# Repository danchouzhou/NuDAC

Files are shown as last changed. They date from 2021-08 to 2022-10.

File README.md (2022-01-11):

# NuDAC
A USB codec based on Nuvoton M482ZGCAE MCU and NAU88L25YGB I2S audio codec
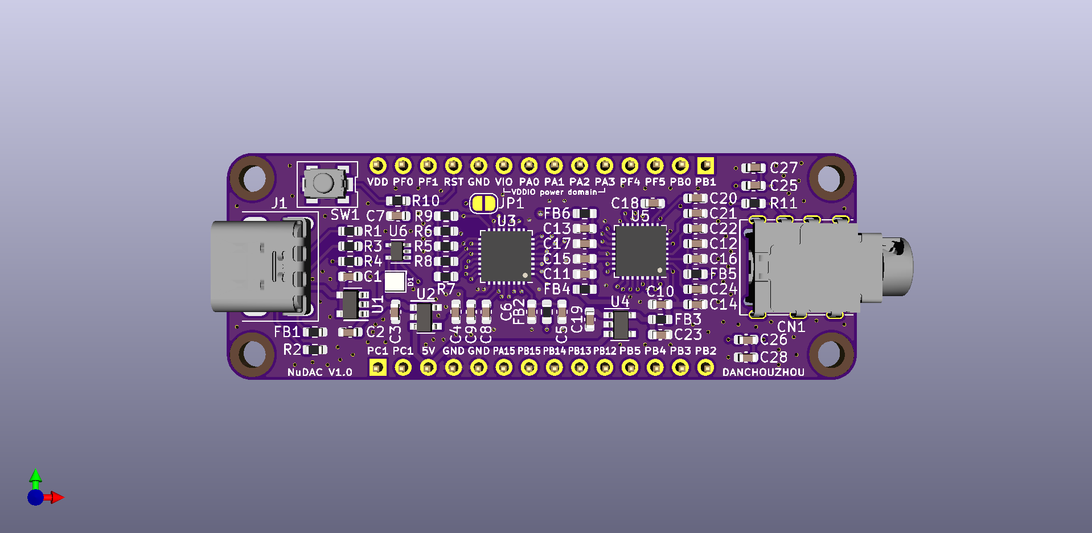
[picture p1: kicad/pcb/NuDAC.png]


## Fetures
### Design
- Provide almost all of MCU I/O on pin header  
- Low noise & fail-safe power design  
- Four-layer PCB  
- Low profile mid mount THT phone jack  
- On board APA ELECTRONIC CO., LTD. patented RGB LED with level translator  
- Molex USB 2.0 through hole Type-C connector improve mechanical strength  
- Jump free Nu-Link connectivity
- Support semi-auto USB ISP (by pressing reset button) provide firmware update and secondary development without a programmer  
### Nuvoton M482ZGCAE microcontroller  
- ARM Cortex-M4 processor up to 192MHz with float point unit and DSP  
- 16-channel programable peripheral direct memory access  
- USB 2.0 full-speed with precise internal oscillator  
- Rich interface include UART, SPI, IIC, IIS, LIN
- 12-bit ADC and DAC
- 16-bit PWM
- True random number generator  
### Nuvoton NAU88L25YGB high performance audio codec
- On chip ground referenced Class-A/AB/G selectable headphone amplifier
- On chip DSP include DRC (Dynamic Range Compressor), and programmable biquad filters  
- 24-bit A/D and D/A signal processing unit, up to 192K sample rate  
- 124dB SNR (@ 1Vrms, 0dB gain, 1KHz)  
- THD+Noise -89dB (@ 32 ohm, 1KHz, 20mW)  
- 28mW output power (@ 32 ohm, 1% THD+N)  

## Specification
- 5V power supply: 4.5~5.5V, 1A max  
- 5V output capacity: 1A max
- VDD output capacity: 300mA max

## To clone this project
This project work with M480BSP submodule from Nuvoton corporation. You need to initialize submodules by passing ``--recurse-submodules`` to the ``git clone`` command.
```
git clone https://github.com/danchouzhou/NuDAC --recurse-submodules
```

## Prepare develop environment
1. Installing tools
```
sudo apt install kicad build-essential gcc-arm-none-eabi libtool libusb-1.0-0-dev
```
2. Build and install customize version of OpenOCD for Nuvoton devices
```
git clone https://github.com/OpenNuvoton/OpenOCD-Nuvoton.git
cd OpenOCD-Nuvoton
./bootstrap
./configure --enable-nulink
make
sudo make install
```

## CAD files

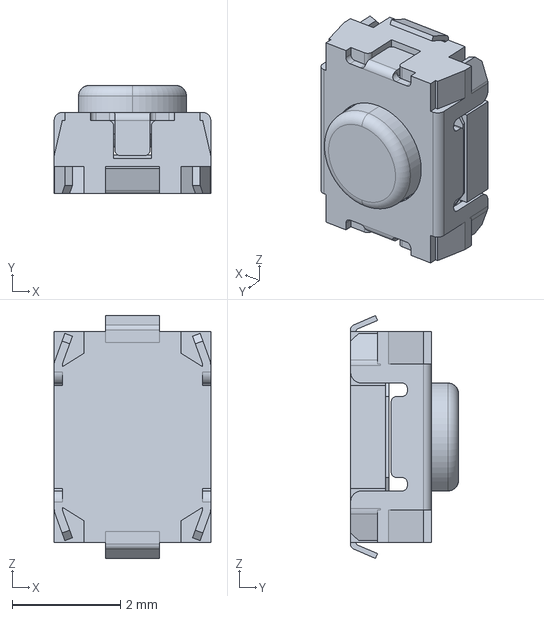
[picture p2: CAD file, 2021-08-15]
kicad/M480/PTS820J25MSMTRLFS.stp
2.90 x 2.00 x 4.50 mm

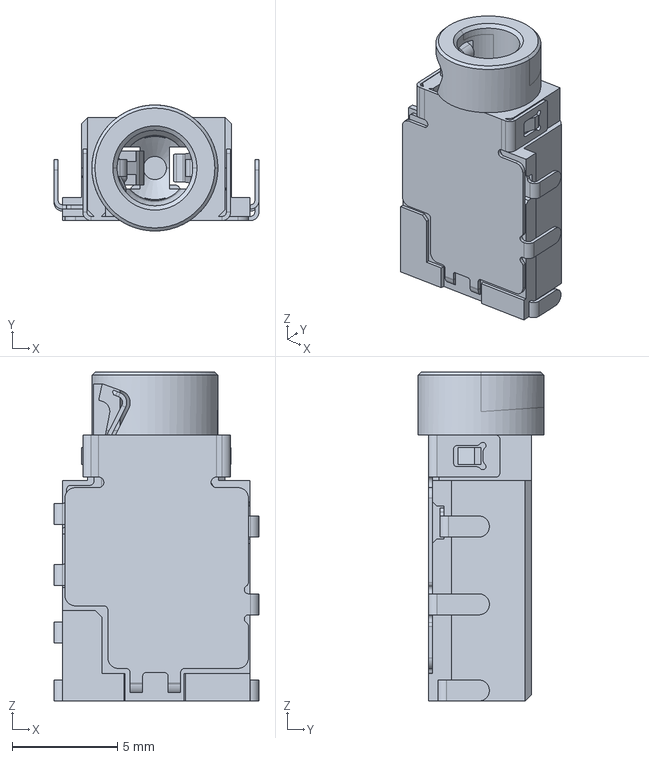
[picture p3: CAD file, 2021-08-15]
kicad/NAU88L25YGB/2SJ3080-000111F.stp
9.75 x 6.00 x 15.7 mm

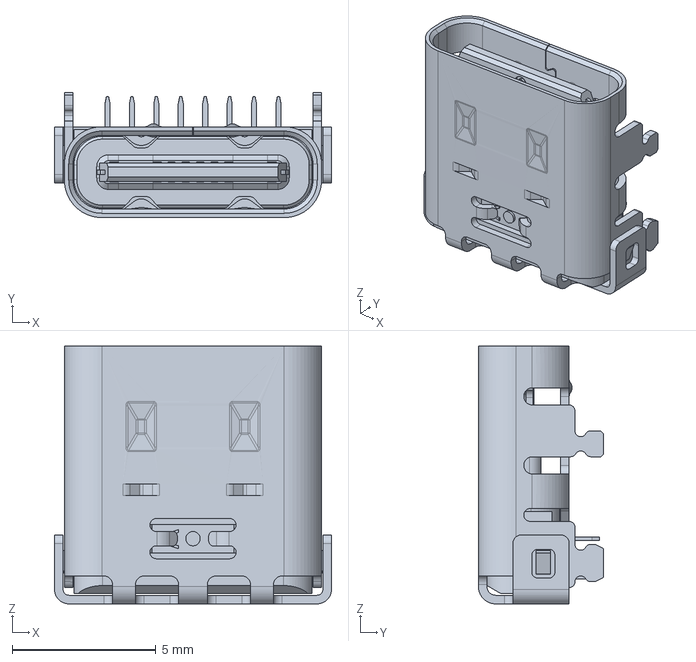
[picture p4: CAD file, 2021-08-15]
kicad/USB_CONN/2137160001.stp
9.64 x 4.36 x 8.97 mm

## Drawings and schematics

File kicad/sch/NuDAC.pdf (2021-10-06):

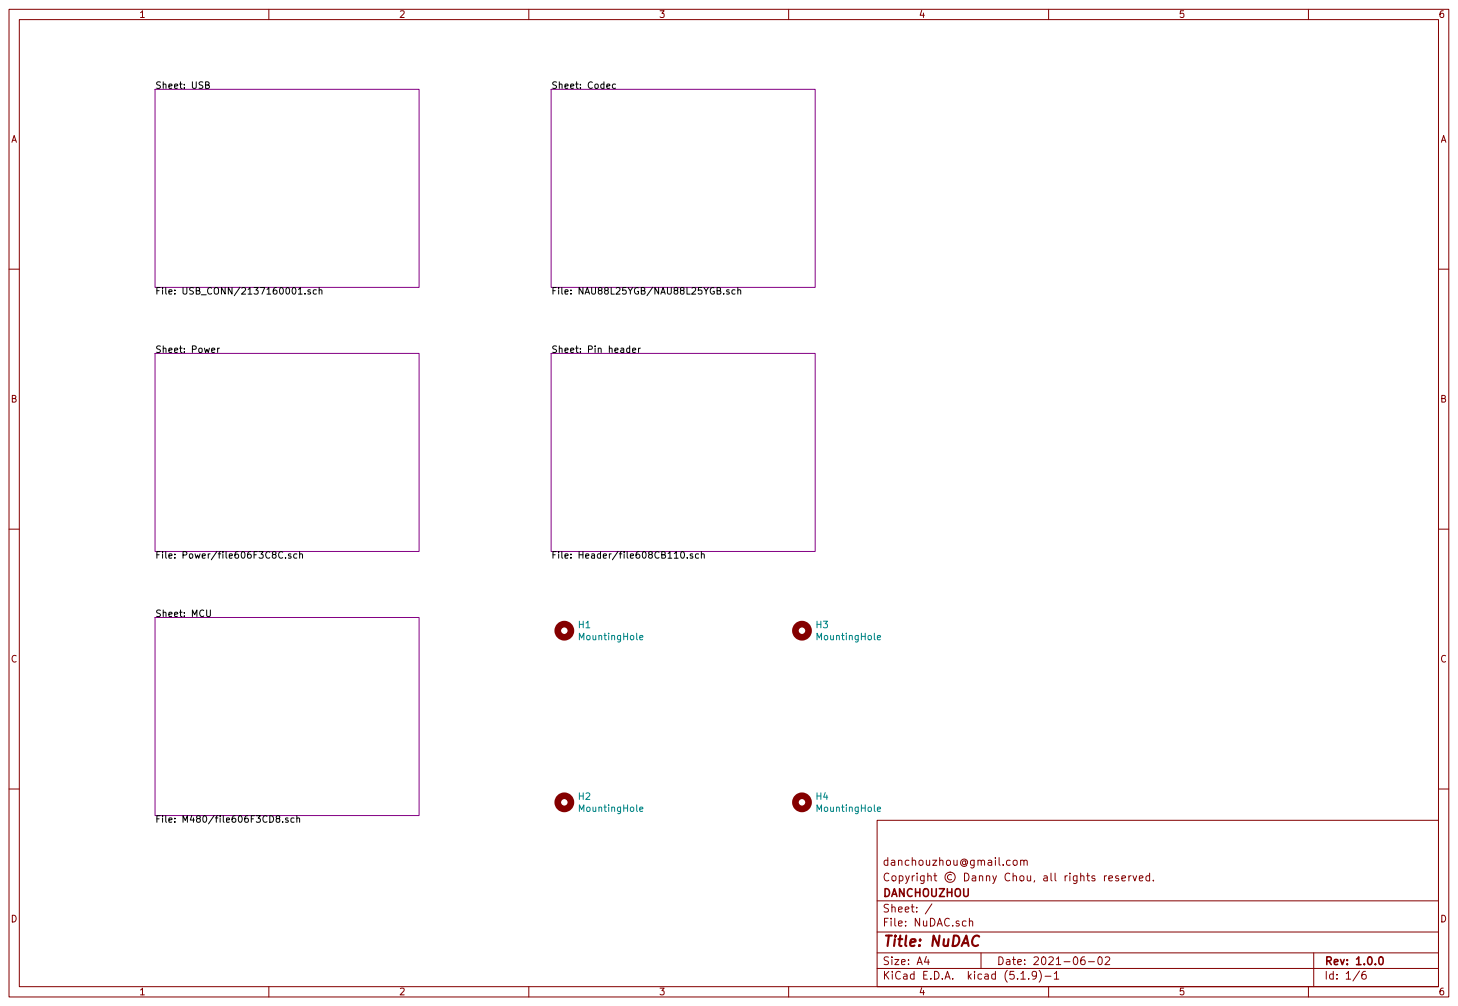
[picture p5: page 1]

File: USB_CONN/2137160001.sch Sheet: Power File: Power/file606F3C8C.sch Sheet: MCU

danchouzhou@gmail.com
Copyright © Danny Chou, all rights reserved.
File: NuDAC.sch Sheet: / DANCHOUZHOU

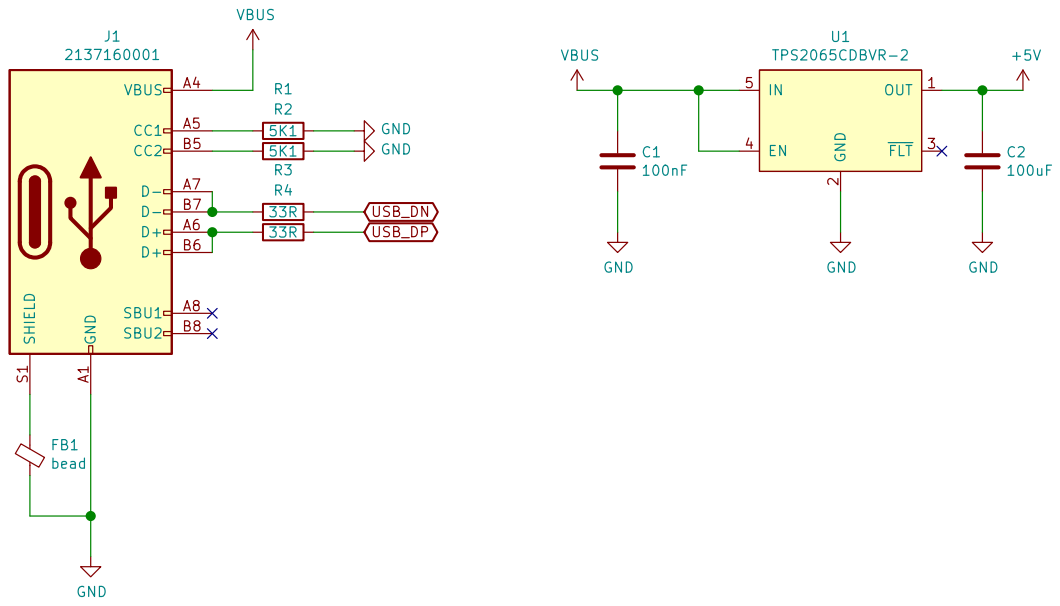
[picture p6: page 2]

danchouzhou@gmail.com
Copyright © Danny Chou, all rights reserved.
File: 2137160001.sch Sheet: /USB/ DANCHOUZHOU

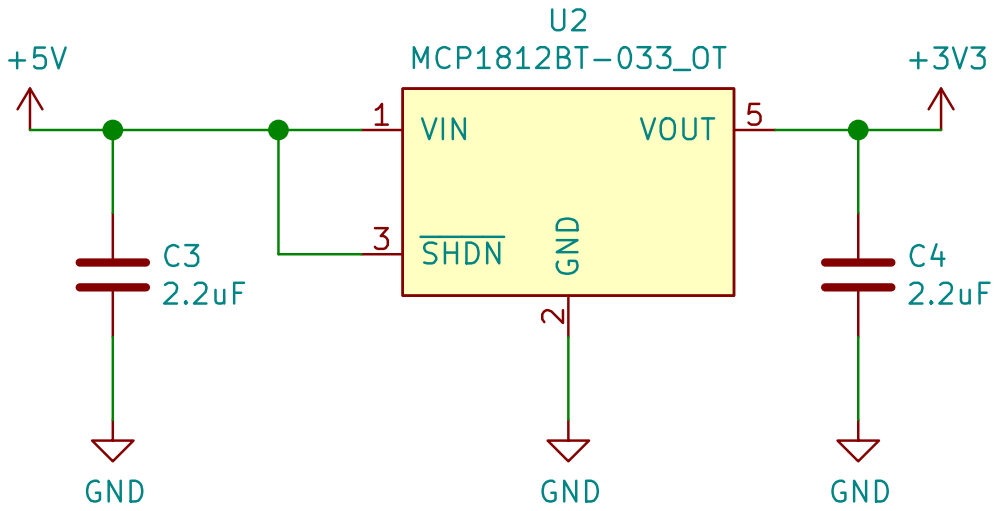
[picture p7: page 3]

danchouzhou@gmail.com
Copyright © Danny Chou, all rights reserved.
File: file606F3C8C.sch Sheet: /Power/ DANCHOUZHOU

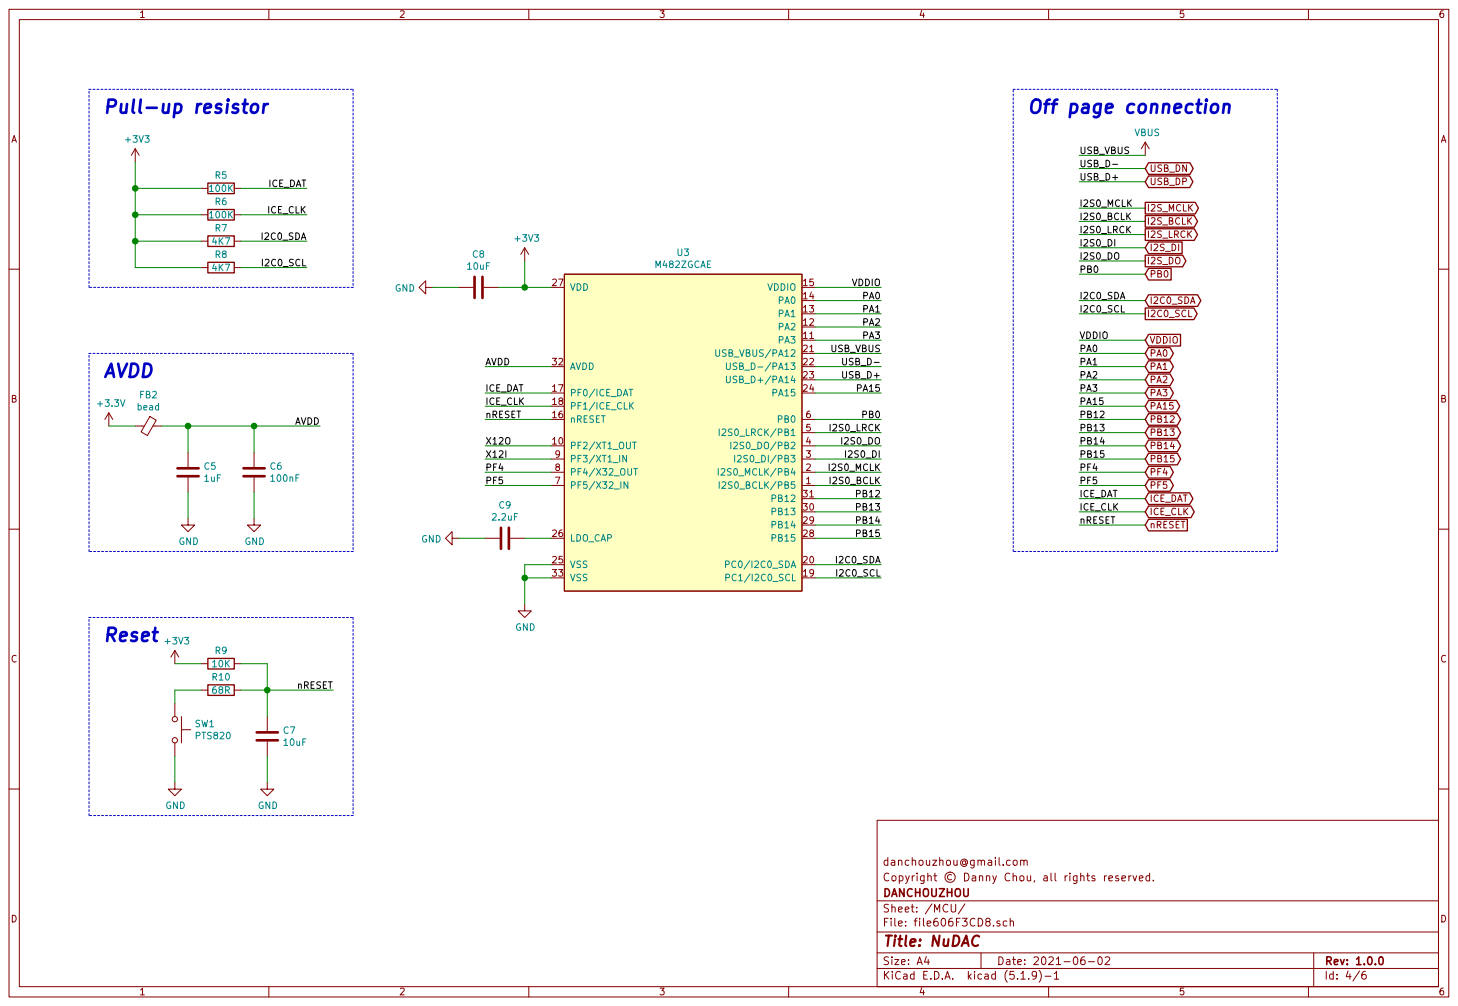
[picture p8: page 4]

danchouzhou@gmail.com
Copyright © Danny Chou, all rights reserved.
File: file606F3CD8.sch Sheet: /MCU/ DANCHOUZHOU

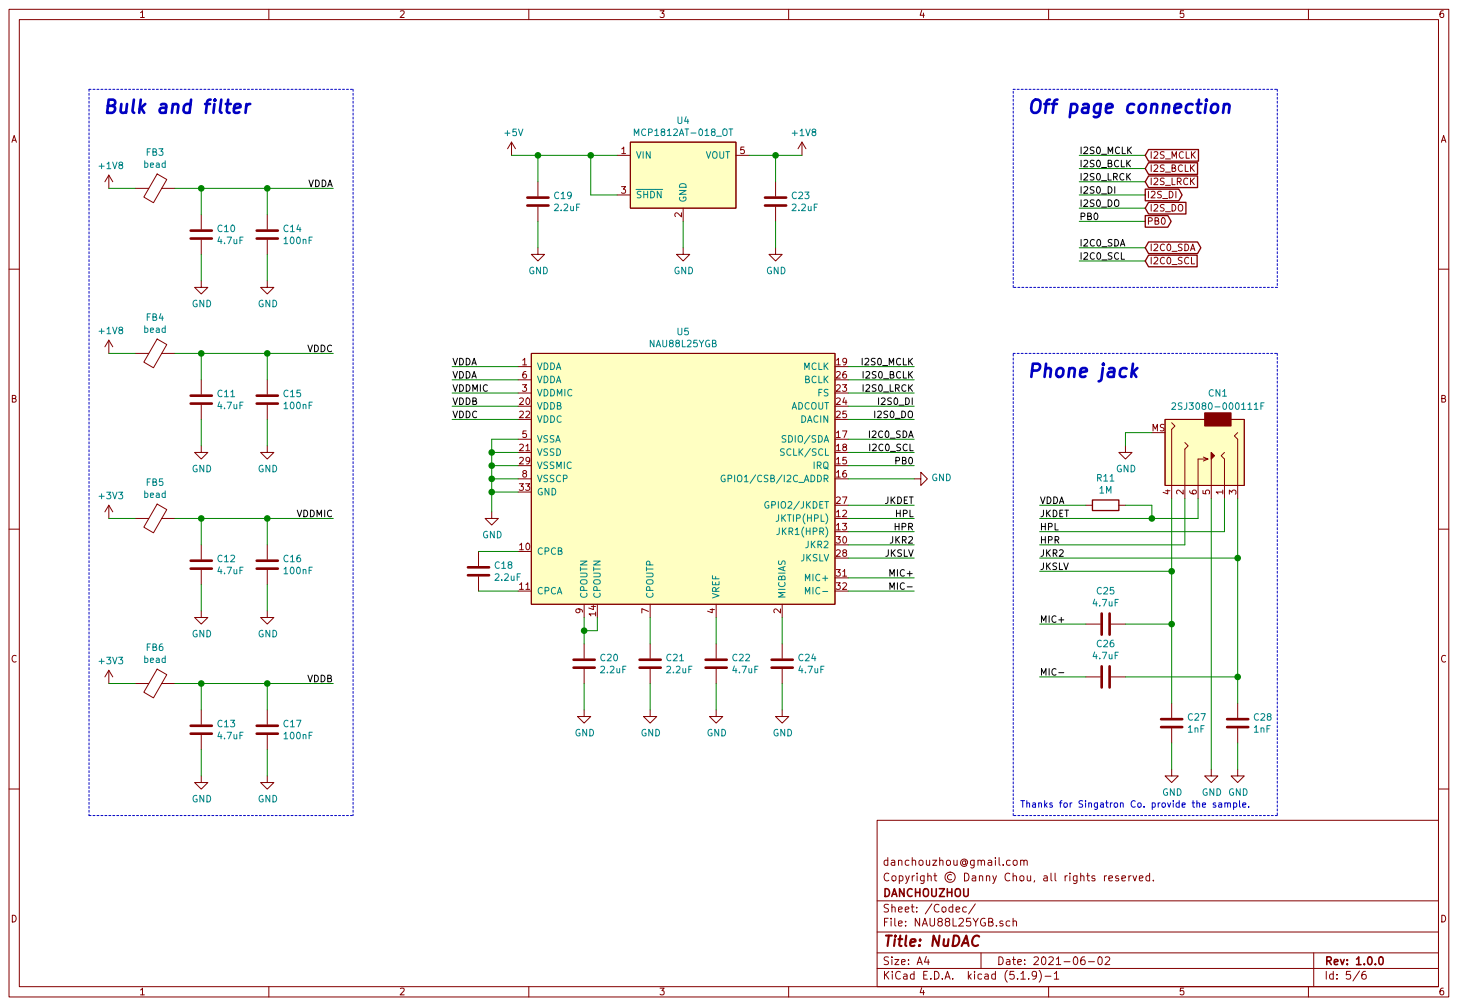
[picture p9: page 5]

2 SHDN 3 VOUT 5 U4 MCP1812AT-018_OT GND GND

Thanks for Singatron Co. provide the sample.

danchouzhou@gmail.com
Copyright © Danny Chou, all rights reserved.
File: NAU88L25YGB.sch Sheet: /Codec/ DANCHOUZHOU

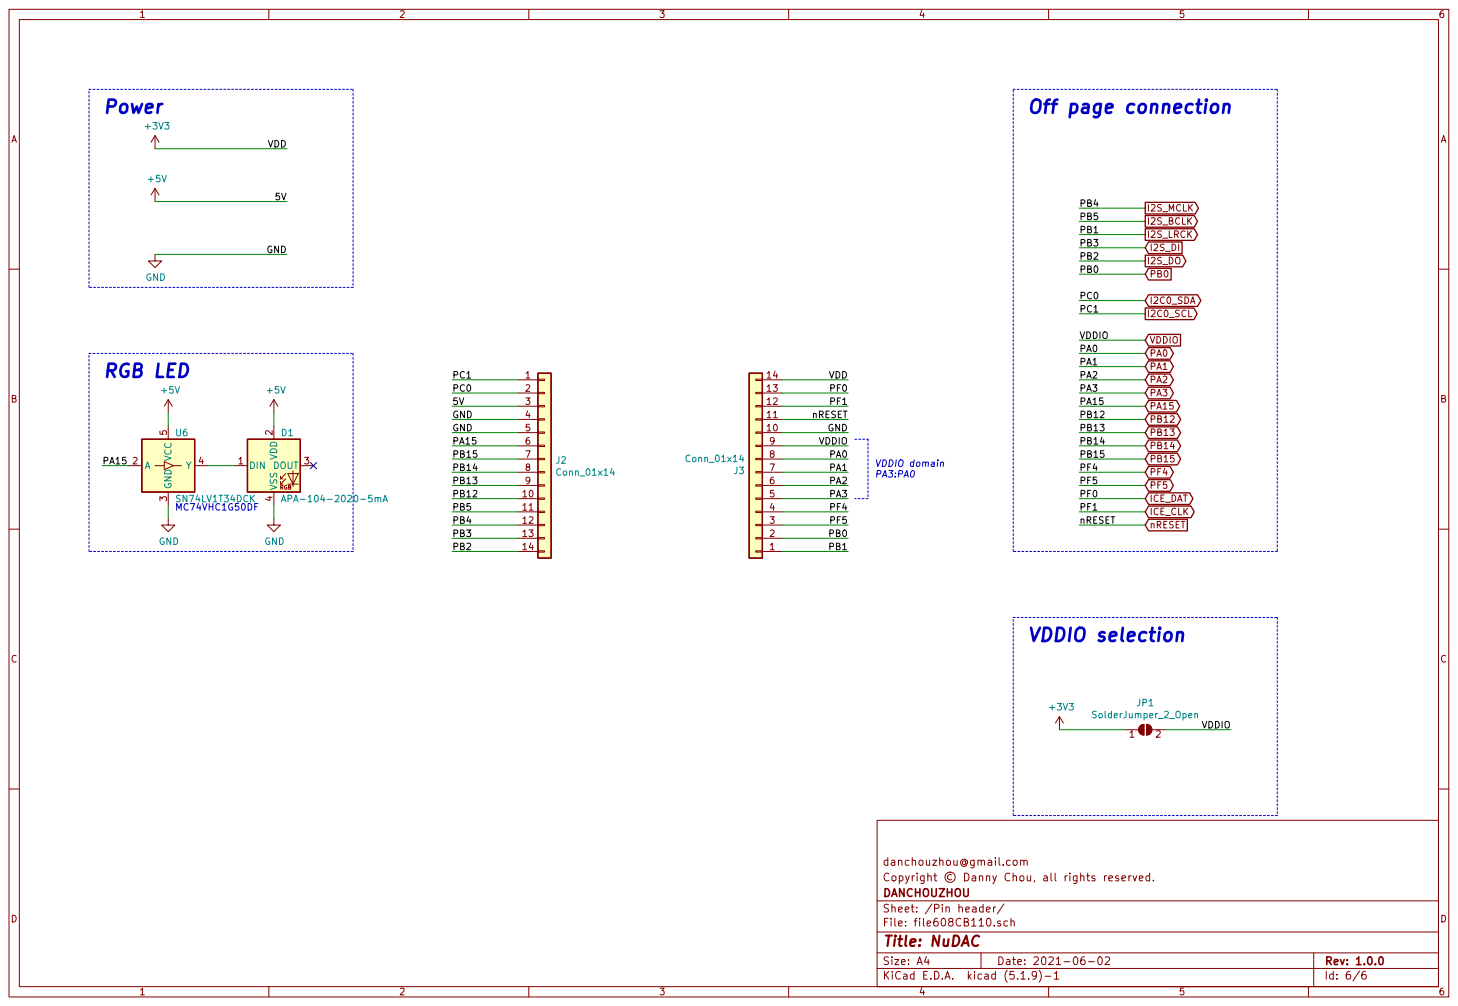
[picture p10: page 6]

danchouzhou@gmail.com
Copyright © Danny Chou, all rights reserved.
File: file608CB110.sch Sheet: /Pin header/ DANCHOUZHOU

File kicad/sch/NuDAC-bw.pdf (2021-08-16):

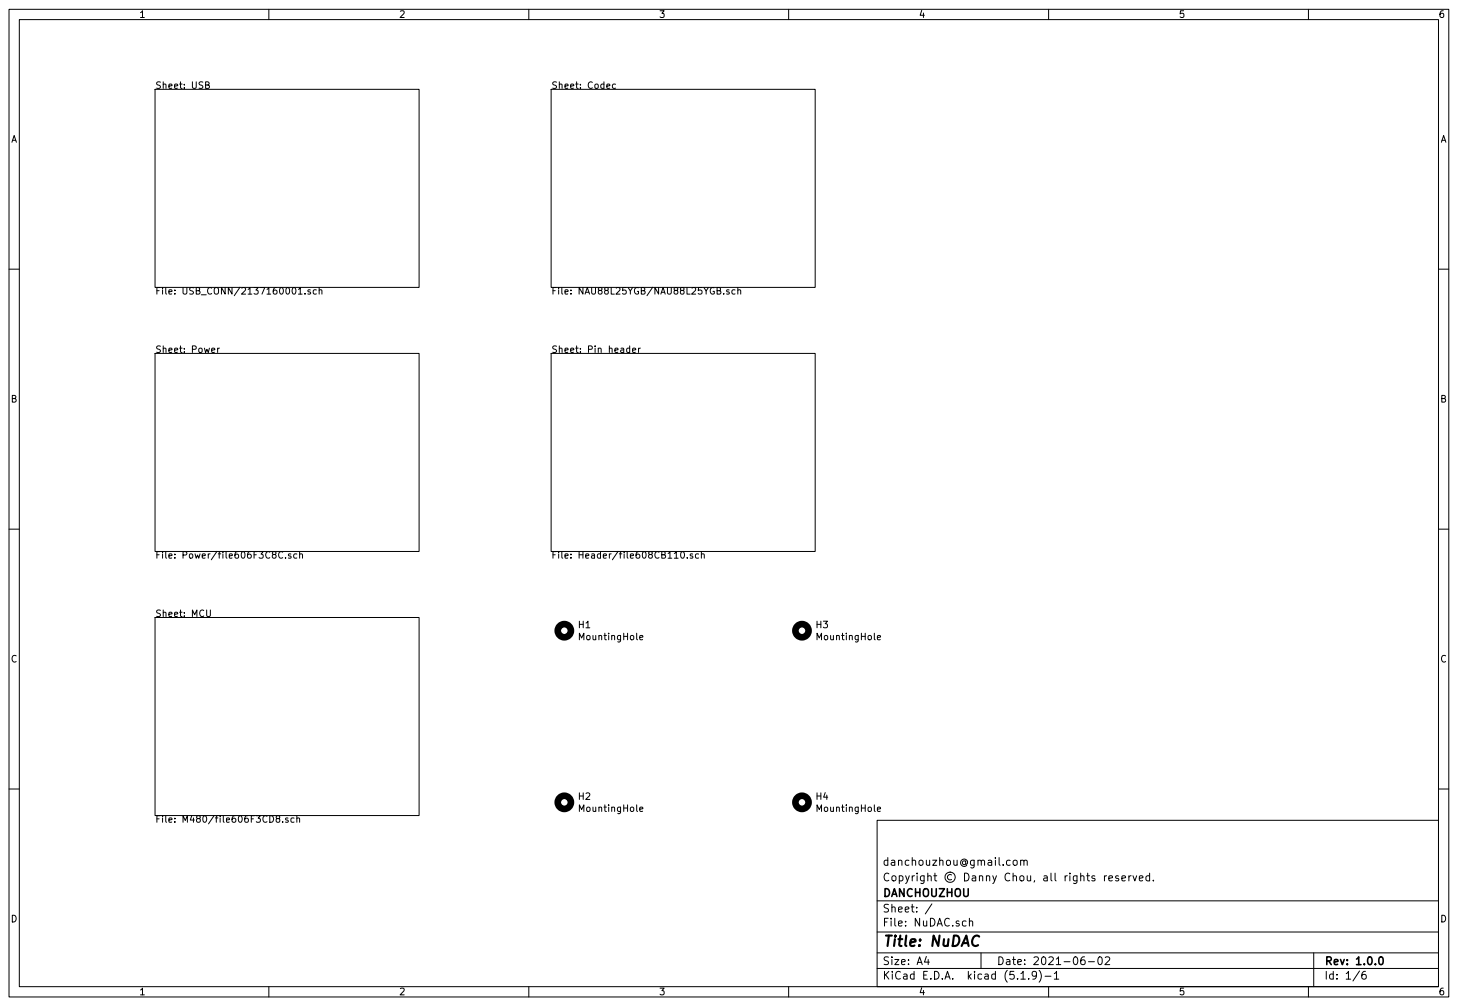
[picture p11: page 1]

File: USB_CONN/2137160001.sch Sheet: Power File: Power/file606F3C8C.sch Sheet: MCU

danchouzhou@gmail.com
Copyright © Danny Chou, all rights reserved.
File: NuDAC.sch Sheet: / DANCHOUZHOU

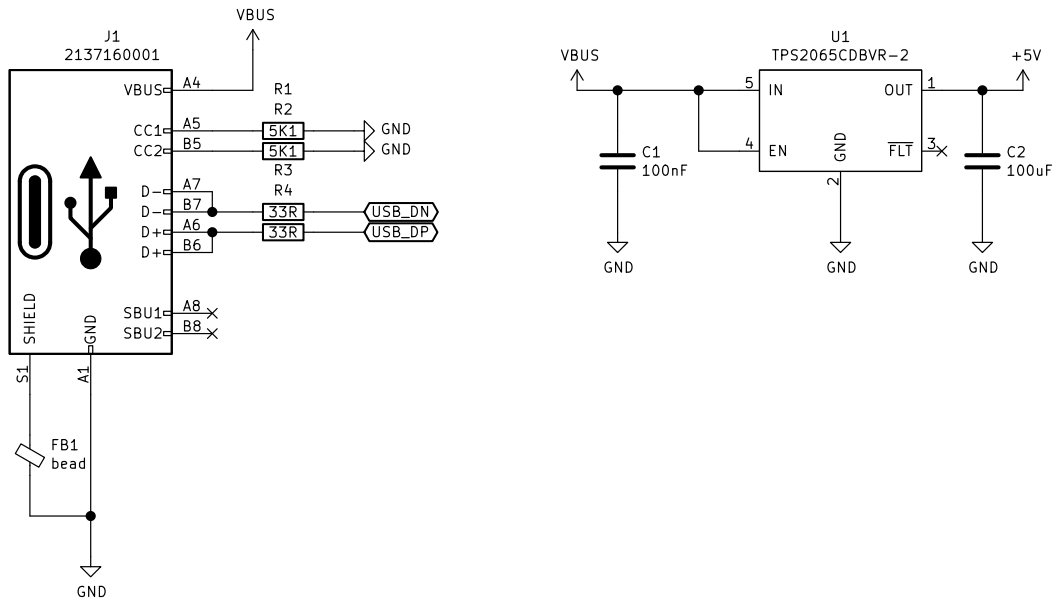
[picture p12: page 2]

danchouzhou@gmail.com
Copyright © Danny Chou, all rights reserved.
File: 2137160001.sch Sheet: /USB/ DANCHOUZHOU

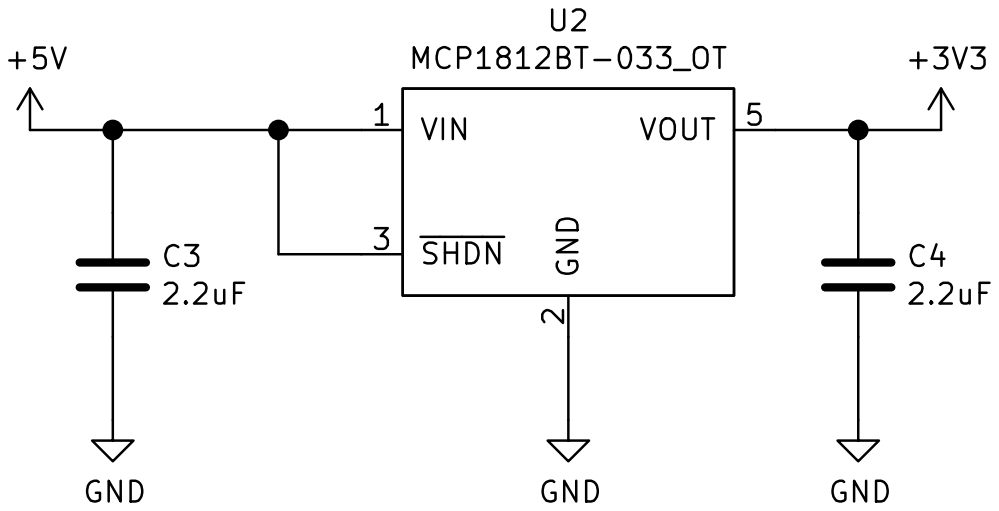
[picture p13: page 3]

danchouzhou@gmail.com
Copyright © Danny Chou, all rights reserved.
File: file606F3C8C.sch Sheet: /Power/ DANCHOUZHOU

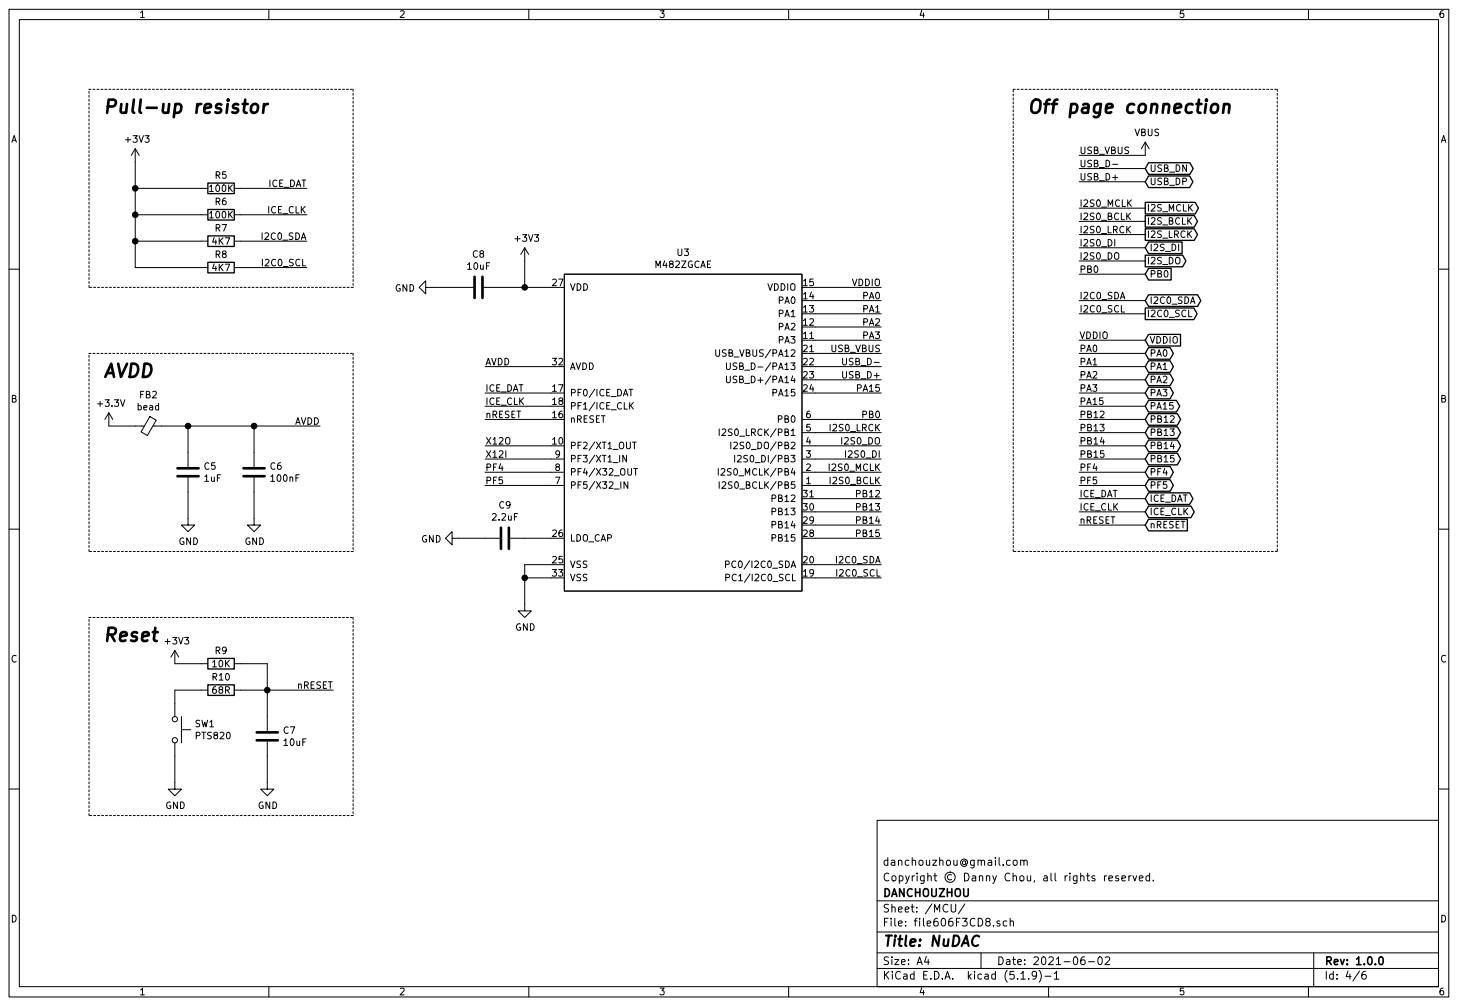
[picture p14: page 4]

danchouzhou@gmail.com
Copyright © Danny Chou, all rights reserved.
File: file606F3CD8.sch Sheet: /MCU/ DANCHOUZHOU

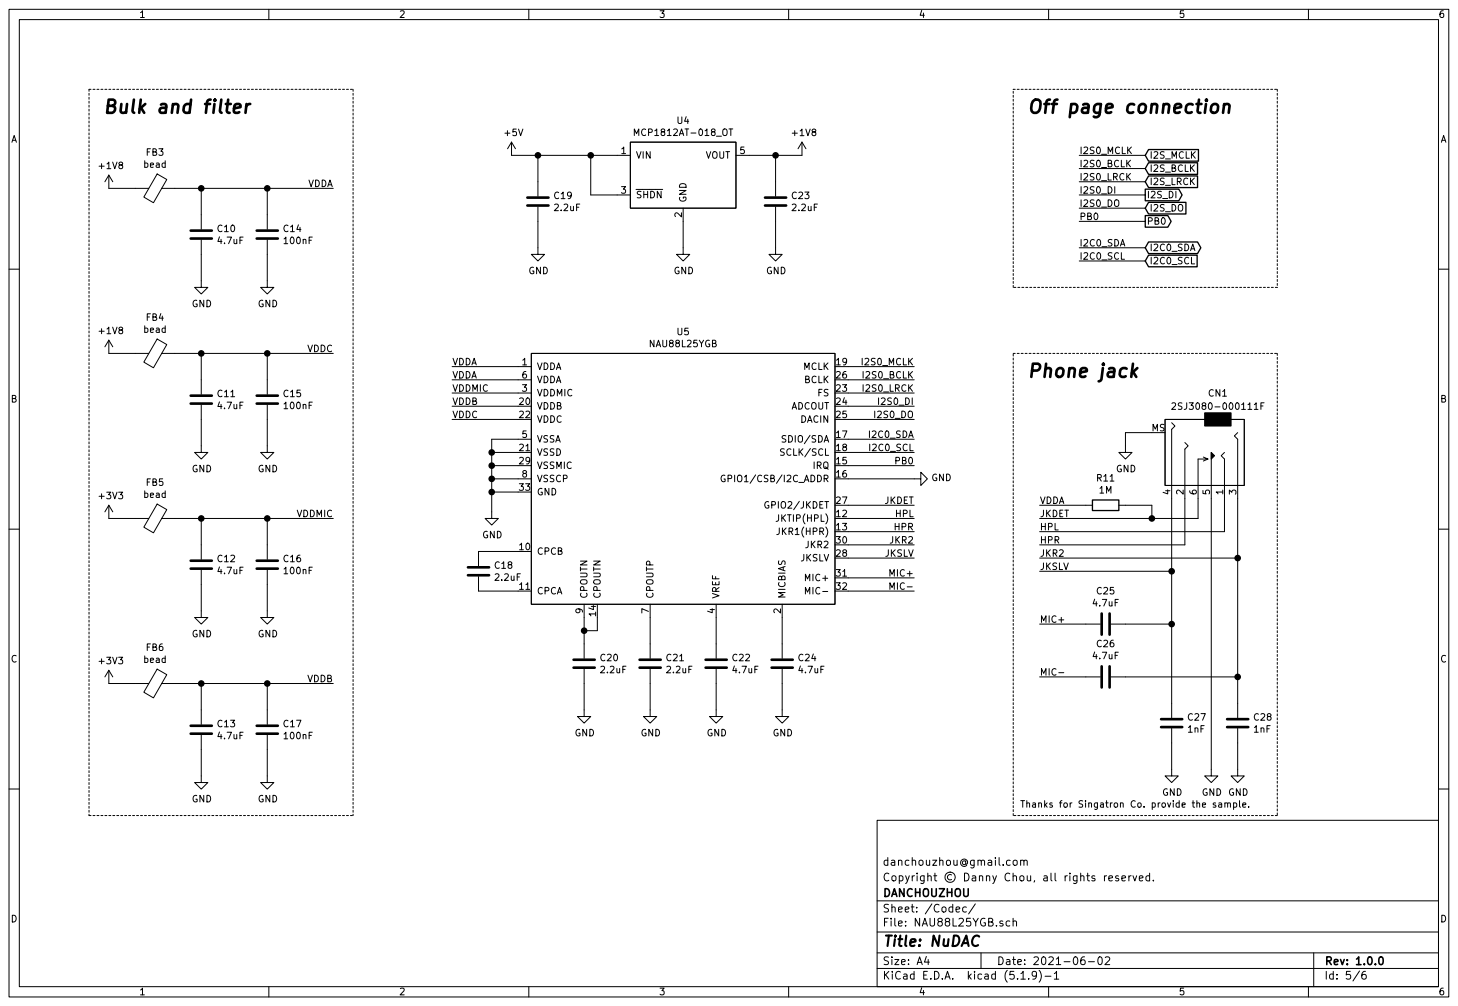
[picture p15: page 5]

2 SHDN 3 VOUT 5 U4 MCP1812AT-018_OT GND GND

Thanks for Singatron Co. provide the sample.

danchouzhou@gmail.com
Copyright © Danny Chou, all rights reserved.
File: NAU88L25YGB.sch Sheet: /Codec/ DANCHOUZHOU

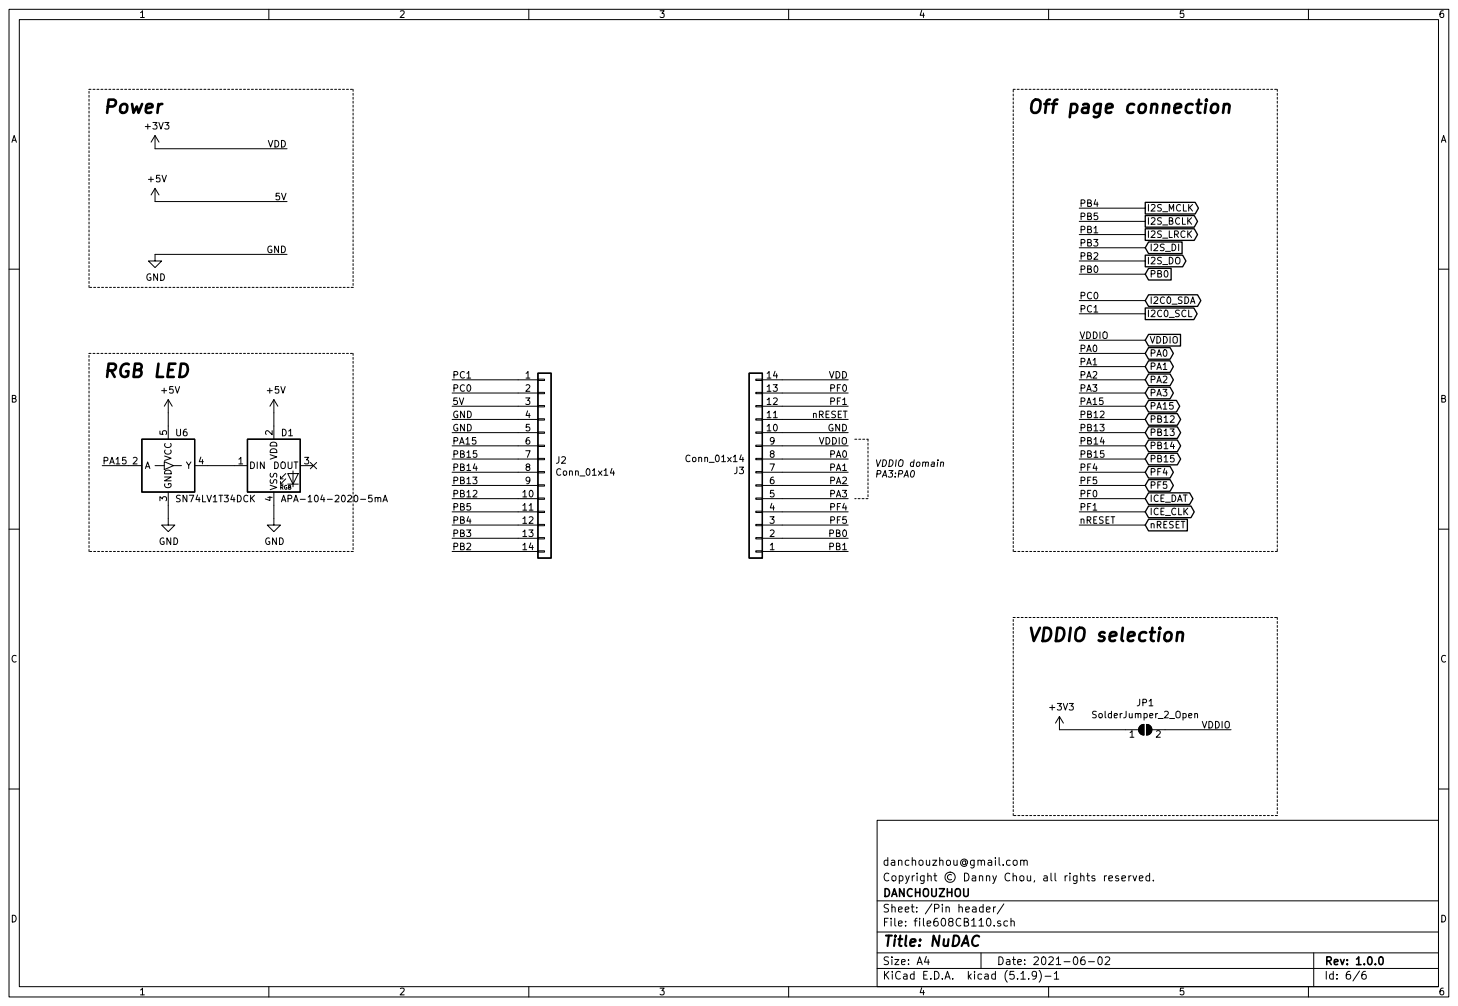
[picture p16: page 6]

VDDIO domain PA3:PA0 RGB LED

danchouzhou@gmail.com
Copyright © Danny Chou, all rights reserved.
File: file608CB110.sch Sheet: /Pin header/ DANCHOUZHOU

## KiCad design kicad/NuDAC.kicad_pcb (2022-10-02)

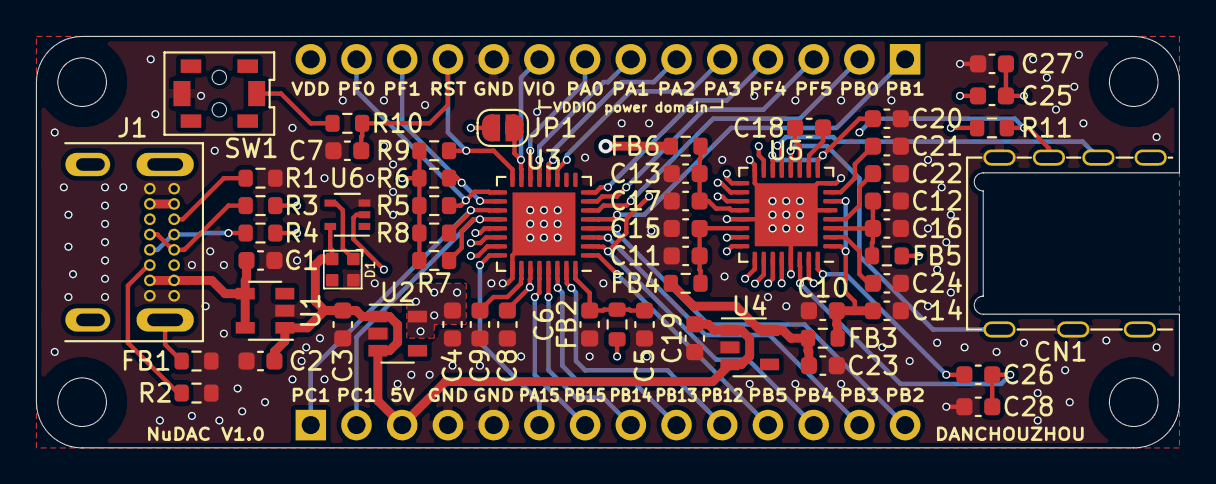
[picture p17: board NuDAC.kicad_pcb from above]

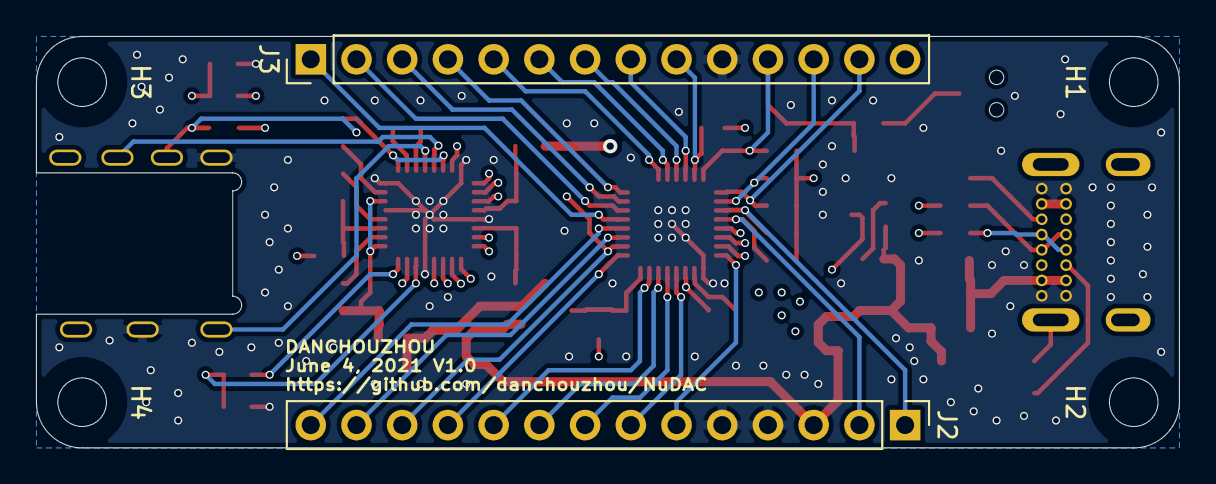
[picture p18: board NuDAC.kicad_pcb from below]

Board: 4 copper layers, 63.5 x 22.9 mm, 62 parts (6 on the bottom side), 56 nets.

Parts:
C1, C6, C14, C15, C16, C17: 100nF; C_0603_1608Metric
C2: 100uF; C_0603_1608Metric
C3, C4, C9, C18, C19, C20, C21, C23: 2.2uF; C_0603_1608Metric
C5: 1uF; C_0603_1608Metric
C7, C8: 10uF; C_0603_1608Metric
C10, C11, C12, C13, C22, C24, C25, C26: 4.7uF; C_0603_1608Metric
C27, C28: 1nF; C_0603_1608Metric
CN1: 2SJ3080-000111F
D1: APA-104-2020-5mA
FB1, FB2, FB3, FB4, FB5, FB6: bead; R_0603_1608Metric
H1, H2, H3, H4: MountingHole; MountingHole_2.7mm_M2.5_ISO7380
J1: 2137160001
J2, J3: Conn_01x14; PinHeader_1x14_P2.54mm_Vertical
JP1: SolderJumper_2_Open; SolderJumper-2_P1.3mm_Open_RoundedPad1.0x1.5mm
R1, R2: 5K1; R_0603_1608Metric
R3, R4: 33R; R_0603_1608Metric
R5, R6: 100K; R_0603_1608Metric
R7, R8: 4K7; R_0603_1608Metric
R9: 10K; R_0603_1608Metric
R10: 68R; R_0603_1608Metric
R11: 1M; R_0603_1608Metric
SW1: PTS820
U1: TPS2065CDBVR-2; SOT-23-5
U2: MCP1812BT-033_OT; SOT-23-5
U3: M482ZGCAE; VQFN-32-1EP_5x5mm_P0.5mm_EP3.5x3.5mm
U4: MCP1812AT-018_OT; SOT-23-5
U5: NAU88L25YGB; VQFN-32-1EP_5x5mm_P0.5mm_EP3.5x3.5mm
U6: SN74LV1T34DCK; SOT-353_SC-70-5

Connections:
+1V8: C23.1, FB3.2, FB4.2, U4.5
+3V3: C4.1, C8.1, FB2.2, FB5.2, FB6.2, J3.14, JP1.1, R5.2, R6.2, R7.2, R8.2, R9.2, U2.5, U3.27
+5V: C2.1, C3.1, C19.1, D1.2, J2.3, U1.1, U2.1, U2.3, U4.1, U4.3, U6.5
/Codec/HPL: CN1.1, U5.12
/Codec/HPR: CN1.2, U5.13
/Codec/JKDET: CN1.6, R11.1, U5.27
/Codec/JKR2: C26.1, C28.1, CN1.3, U5.30
/Codec/JKSLV: C25.1, C27.1, CN1.4, U5.28
/Codec/MIC+: C25.2, U5.31
/Codec/MIC-: C26.2, U5.32
/Codec/VDDA: C10.1, C14.1, FB3.1, R11.2, U5.1, U5.6
/Codec/VDDB: C13.1, C17.1, FB6.1, U5.20
/Codec/VDDC: C11.1, C15.1, FB4.1, U5.22
/Codec/VDDMIC: C12.1, C16.1, FB5.1, U5.3
/MCU/AVDD: C5.1, C6.1, FB2.1, U3.32
GND: C1.2, C2.2, C3.2, C4.2, C5.2, C6.2, C7.2, C8.2, C9.2, C10.2, C11.2, C12.2, C13.2, C14.2, C15.2, C16.2, C17.2, C19.2, C20.2, C21.2, C22.2, C23.2, C24.2, C27.2, C28.2, CN1.5, CN1.MS, D1.4, FB1.1, J1.A1, J1.A12, J1.B1, J1.B12, J2.4, J2.5, J3.10, R1.1, R2.1, SW1.2, U1.2, U2.2, U3.25, U3.33, U4.2, U5.5, U5.8, U5.16, U5.21, U5.29, U5.33, U6.3
I2C0_SCL: J2.1, R8.1, U3.19, U5.18
I2C0_SDA: J2.2, R7.1, U3.20, U5.17
I2S_BCLK: J2.11, U3.1, U5.26
I2S_DI: J2.13, U3.3, U5.24
I2S_DO: J2.14, U3.4, U5.25
I2S_LRCK: J3.1, U3.5, U5.23
I2S_MCLK: J2.12, U3.2, U5.19
ICE_CLK: J3.12, R6.1, U3.18
ICE_DAT: J3.13, R5.1, U3.17
unnamed: C9.1, U3.26
unnamed: C18.1, U5.10
unnamed: C18.2, U5.11
unnamed: C20.1, U5.9, U5.14
unnamed: C21.1, U5.7
unnamed: C22.1, U5.4
unnamed: C24.1, U5.2
unnamed: D1.1, U6.4
unnamed: FB1.2, J1.S1
unnamed: J1.A5, R1.2
unnamed: J1.A6, J1.B6, R4.2
unnamed: J1.A7, J1.B7, R3.2
unnamed: J1.B5, R2.2
unnamed: R10.2, SW1.1
PA0: J3.8, U3.14
PA1: J3.7, U3.13
PA2: J3.6, U3.12
PA3: J3.5, U3.11
PA15: J2.6, U3.24, U6.2
PB0: J3.2, U3.6, U5.15
PB12: J2.10, U3.31
PB13: J2.9, U3.30
PB14: J2.8, U3.29
PB15: J2.7, U3.28
PF4: J3.4, U3.8
PF5: J3.3, U3.7
USB_DN: R3.1, U3.22
USB_DP: R4.1, U3.23
VBUS: C1.1, J1.A4, J1.A9, J1.B4, J1.B9, U1.4, U1.5, U3.21
VDDIO: J3.9, JP1.2, U3.15
nRESET: C7.1, J3.11, R9.1, R10.1, U3.16

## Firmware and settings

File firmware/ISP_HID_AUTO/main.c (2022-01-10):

/***************************************************************************//**
 * @file     main.c
 * @brief    ISP tool main function
 * @version  0x32
 * @date     14, June, 2017
 *
 * @note
 * Copyright (C) 2017-2018 Nuvoton Technology Corp. All rights reserved.
 ******************************************************************************/
#include <stdio.h>
#include "targetdev.h"
#include "hid_transfer.h"
#include "isp_user.h"

#define PLLCON_SETTING          CLK_PLLCTL_192MHz_HIRC
#define PLL_CLOCK               192000000
#define HCLK_DIV                        1
#define USBD_DIV                        4
#define CRYSTAL_LESS                    1

uint32_t CLK_GetPLLClockFreq(void)
{
    return PLL_CLOCK;
}

/*--------------------------------------------------------------------------*/
void SYS_Init(void)
{
    /*---------------------------------------------------------------------------------------------------------*/
    /* Init System Clock                                                                                       */
    /*---------------------------------------------------------------------------------------------------------*/

    /* Enable Internal RC clock */
    CLK->PWRCTL |= CLK_PWRCTL_HIRCEN_Msk;

    /* Waiting for internal RC clock ready */
    while (!(CLK->STATUS & CLK_STATUS_HIRCSTB_Msk));

    /* Set core clock as PLL_CLOCK from PLL */
    CLK->PLLCTL = PLLCON_SETTING;

    /* Waiting for PLL clock ready */
    while (!(CLK->STATUS & CLK_STATUS_PLLSTB_Msk));

    /* Select HCLK */
    CLK->CLKSEL0 = (CLK->CLKSEL0 & ~(CLK_CLKSEL0_HCLKSEL_Msk)) | CLK_CLKSEL0_HCLKSEL_PLL;
    CLK->CLKDIV0 = (CLK->CLKDIV0 & ~(CLK_CLKDIV0_HCLKDIV_Msk)) | CLK_CLKDIV0_HCLK(HCLK_DIV);

    /* M480LD support crystal-less */
    if (((SYS->CSERVER & SYS_CSERVER_VERSION_Msk) == 0x1) && (CRYSTAL_LESS))
    {
        /* Enable Internal RC Oscillator (48MHz) */
        CLK->PWRCTL |= CLK_PWRCTL_HIRC48MEN_Msk;
        /* Select IP clock source */
        CLK->CLKSEL0 &= ~CLK_CLKSEL0_USBSEL_Msk;
    }
    else
    {
        /* Select IP clock source */
        CLK->CLKSEL0 |= CLK_CLKSEL0_USBSEL_Msk;
        CLK->CLKDIV0 = (CLK->CLKDIV0 & ~CLK_CLKDIV0_USBDIV_Msk) | CLK_CLKDIV0_USB(4);
    }

    /* SysTick clock source HIRC 12MHz / 2 = 6MHz */
    CLK->CLKSEL0 = (CLK->CLKSEL0 & ~CLK_CLKSEL0_STCLKSEL_Msk) | CLK_CLKSEL0_STCLKSEL_HIRC_DIV2;

    /* Update System Core Clock */
    /* User can use SystemCoreClockUpdate() to calculate PllClock, SystemCoreClock and CycylesPerUs automatically. */
    //SystemCoreClockUpdate();
    PllClock        = PLL_CLOCK;                        // PLL
    SystemCoreClock = PLL_CLOCK / HCLK_DIV;             // HCLK
    CyclesPerUs     = SystemCoreClock / 1000000;  // For SYS_SysTickDelay()

    /* Set both PCLK0 and PCLK1 as HCLK/2 */
    CLK->PCLKDIV = CLK_PCLKDIV_APB0DIV_DIV2 | CLK_PCLKDIV_APB1DIV_DIV2;

    /* Select USBD */
    SYS->USBPHY = (SYS->USBPHY & ~SYS_USBPHY_USBROLE_Msk) | SYS_USBPHY_USBEN_Msk | SYS_USBPHY_SBO_Msk;

    /* Enable module clock */
    CLK->APBCLK0 |= CLK_APBCLK0_USBDCKEN_Msk;
    CLK->AHBCLK |= CLK_AHBCLK_ISPCKEN_Msk;

    /*---------------------------------------------------------------------------------------------------------*/
    /* Init I/O Multi-function                                                                                 */
    /*---------------------------------------------------------------------------------------------------------*/
    /* Set PA.12 ~ PA.14 to input mode */
    PA->MODE &= ~(GPIO_MODE_MODE12_Msk | GPIO_MODE_MODE13_Msk | GPIO_MODE_MODE14_Msk);
    SYS->GPA_MFPH &= ~(SYS_GPA_MFPH_PA12MFP_Msk | SYS_GPA_MFPH_PA13MFP_Msk | SYS_GPA_MFPH_PA14MFP_Msk);
    SYS->GPA_MFPH |= (SYS_GPA_MFPH_PA12MFP_USB_VBUS | SYS_GPA_MFPH_PA13MFP_USB_D_N | SYS_GPA_MFPH_PA14MFP_USB_D_P);
}

void NeoPixelShow_HCLK_192MHz(volatile uint32_t *pu32pdio, uint32_t u32color)
{
    uint32_t bitMask = 0x800000;
    uint32_t t0, t1, top, ticks, saveLoad, saveVal, saveCtrl;

    GPIO_T *port;
    uint32_t pin;

    /* Get port and pin from PDIO */
    port = (GPIO_T *)( ( ( (uint32_t)pu32pdio - GPIO_PIN_DATA_BASE) & 0x1C0) + GPIOA_BASE);
    pin = ( ( (uint32_t)pu32pdio - GPIO_PIN_DATA_BASE) & 0x3F) >> 2;

    port->MODE = (port->MODE & ~( (GPIO_MODE_QUASI) << ( (pin)<<1)) | ( (GPIO_MODE_OUTPUT) << ( (pin)<<1)));

    *pu32pdio = 0; // PDIO output low

    /* No needed in polling mode */
    /* Disable all interrupts force the timming */
    //__disable_irq();

    saveLoad = SysTick->LOAD; 
    saveVal = SysTick->VAL;
    saveCtrl = SysTick->CTRL;

    // Wait for 300us present a reset sequence
    SysTick->LOAD = 57600; // 192MHz * 300
    SysTick->VAL  = (0x00);

    /* Switch the clock source to HCLK and enable SysTick Timer */
    SysTick->CTRL = SysTick_CTRL_CLKSOURCE_Msk | SysTick_CTRL_ENABLE_Msk;

    /* Waiting for down-count to zero */
    while ((SysTick->CTRL & SysTick_CTRL_COUNTFLAG_Msk) == 0);

    /*
    F_CPU = CLK_GetCPUFreq();

    top =       (uint32_t)(F_CPU * 0.00000125); // Bit hi + lo = 1.25 uS
    t0  = top - (uint32_t)(F_CPU * 0.00000040); // 0 = 0.4 uS hi
    t1  = top - (uint32_t)(F_CPU * 0.00000080); // 1 = 0.8 uS hi
    */
    top = 240;
    t0 = 164;
    t1 = 87;   
    
    SysTick->LOAD = top;               // Config SysTick for NeoPixel bit freq
    SysTick->VAL  = top;               // Set to start value (counts down)
    (void)SysTick->VAL;                // Dummy read helps sync up 1st bit

    for(;;) {
        *pu32pdio  = 1;                         // Set output high
        ticks = (u32color & bitMask) ? t1 : t0; // SysTick threshold,
        while(SysTick->VAL > ticks);            // wait for it
        *pu32pdio  = 0;                         // Set output low
        if(!(bitMask >>= 1)) {                  // Next bit for this color...done?
            break;                              // Exit the loop
        }
        while(SysTick->VAL <= ticks);           // Wait for rollover to 'top'
    }

    /* Restore SysTick config */
    SysTick->LOAD = saveLoad;
    SysTick->VAL  = saveVal;
    SysTick->CTRL = saveCtrl;

    /* Turn the interrupt back */
    //__enable_irq();
}

void USBD_IRQHandler(void);
/*---------------------------------------------------------------------------------------------------------*/
/*  Main Function                                                                                          */
/*---------------------------------------------------------------------------------------------------------*/
int32_t main(void)
{
    volatile uint32_t u32TimeOutCnt = 0;
    /* Unlock write-protected registers */
    SYS_UnlockReg();
    /* Init system and multi-function I/O */
    SYS_Init();
    FMC->ISPCTL |= FMC_ISPCTL_ISPEN_Msk;    // (1ul << 0)
    g_apromSize = GetApromSize();
    GetDataFlashInfo(&g_dataFlashAddr, &g_dataFlashSize);

    /* Open USB controller */
    USBD_Open(&gsInfo, HID_ClassRequest, NULL);
    /*Init Endpoint configuration for HID */
    HID_Init();
    /* Start USB device */
    USBD_Start();

    /* Using polling mode and Removed Interrupt Table to reduce code size for M480 */

    /* DO NOT Enable USB device interrupt */
    // NVIC_EnableIRQ(USBD_IRQn);

    while(u32TimeOutCnt++ < 30) // perform three seconds
    {
        //SysTick->LOAD = 100000 * CyclesPerUs; // 0.1 second
        SysTick->LOAD = 600000;
        SysTick->VAL  = (0x00);
        SysTick->CTRL = SysTick_CTRL_ENABLE_Msk;

        if(u32TimeOutCnt & 0x1)
            NeoPixelShow_HCLK_192MHz(&PA15, 0x1400); // Red
        else
            NeoPixelShow_HCLK_192MHz(&PA15, 0x0);

        while ( (g_u8Connected == 0) || ((SysTick->CTRL & SysTick_CTRL_COUNTFLAG_Msk) == 0))
        {
            // polling USBD interrupt flag
            USBD_IRQHandler();

            if (bUsbDataReady == TRUE)
            {
                NeoPixelShow_HCLK_192MHz(&PA15, 0x120000); // Green
                ParseCmd((uint8_t *)usb_rcvbuf, 64);
                EP2_Handler();
                bUsbDataReady = FALSE;
            }
        }
        
        /* Disable SysTick counter */
        SysTick->CTRL = 0;
    }

    /* Pin data I/O, color 0xGGRRBB */
    NeoPixelShow_HCLK_192MHz(&PA15, 0x020c0c); // Purple

    SysTick->LOAD = 1800;  // wait 300us
    SysTick->VAL  = (0x00);
    SysTick->CTRL = SysTick_CTRL_ENABLE_Msk;

    /* Waiting for down-count to zero */
    while ((SysTick->CTRL & SysTick_CTRL_COUNTFLAG_Msk) == 0);

    outpw(&SYS->RSTSTS, 3);//clear bit
    outpw(&FMC->ISPCTL, inpw(&FMC->ISPCTL) & 0xFFFFFFFC);
    outpw(&SCB->AIRCR, (V6M_AIRCR_VECTKEY_DATA | V6M_AIRCR_SYSRESETREQ));

    /* Trap the CPU */
    while (1);

    return 0;
}
/*** (C) COPYRIGHT 2017 Nuvoton Technology Corp. ***/

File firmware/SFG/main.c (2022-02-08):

#include <stdio.h>
#include "NuMicro.h"
#include <math.h>
#include "arm_math.h"
#include "audio_codec.h"

#define CRYSTAL_LESS        1

void SYS_Init(void)
{
    /* Enable Internal RC Oscillator (12MHz) */
    CLK_EnableXtalRC(CLK_PWRCTL_HIRCEN_Msk);

    /* Waiting for 12MHz clock ready */
    CLK_WaitClockReady(CLK_STATUS_HIRCSTB_Msk);

    /* Set core clock as PLL_CLOCK from PLL */
    CLK_SetCoreClock(FREQ_192MHZ);

    /* M480LD support crystal-less */
    if (((SYS->CSERVER & SYS_CSERVER_VERSION_Msk) == 0x1) && (CRYSTAL_LESS))
    {
        /* Enable Internal RC Oscillator (48MHz) */
        CLK->PWRCTL |= CLK_PWRCTL_HIRC48MEN_Msk;
        /* Select IP clock source */
        CLK->CLKSEL0 &= ~CLK_CLKSEL0_USBSEL_Msk;
    }
    else
    {
        /* Select IP clock source */
        CLK->CLKSEL0 |= CLK_CLKSEL0_USBSEL_Msk;
        CLK->CLKDIV0 = (CLK->CLKDIV0 & ~CLK_CLKDIV0_USBDIV_Msk) | CLK_CLKDIV0_USB(4);
    }

    /* Update System Core Clock */
    /* User can use SystemCoreClockUpdate() to calculate SystemCoreClock. */
    SystemCoreClockUpdate();

    /* Set both PCLK0 and PCLK1 as HCLK/2 */
    CLK->PCLKDIV = CLK_PCLKDIV_APB0DIV_DIV2 | CLK_PCLKDIV_APB1DIV_DIV2;

    /* Select USBD */
    SYS->USBPHY = (SYS->USBPHY & ~SYS_USBPHY_USBROLE_Msk) | SYS_USBPHY_USBEN_Msk | SYS_USBPHY_SBO_Msk;

    /* Enable IP clock */
    CLK_EnableModuleClock(USBD_MODULE);

    /* Select IP clock source */
    CLK_SetModuleClock(UART0_MODULE, CLK_CLKSEL1_UART0SEL_HIRC, CLK_CLKDIV0_UART0(1));
    CLK_SetModuleClock(I2S0_MODULE, CLK_CLKSEL3_I2S0SEL_HIRC, CLK_CLKDIV2_I2S0(1));

    /* Enable IP clock */
    CLK_EnableModuleClock(UART0_MODULE);
    CLK_EnableModuleClock(I2C0_MODULE);
    CLK_EnableModuleClock(I2S0_MODULE);

    /* Set PA.12 ~ PA.14 to input mode */
    PA->MODE &= ~(GPIO_MODE_MODE12_Msk | GPIO_MODE_MODE13_Msk | GPIO_MODE_MODE14_Msk);
    /* Set GPA multi-function pins for USB */
    SYS->GPA_MFPH &= ~(SYS_GPA_MFPH_PA12MFP_Msk | SYS_GPA_MFPH_PA13MFP_Msk | SYS_GPA_MFPH_PA14MFP_Msk);
    SYS->GPA_MFPH |=  (SYS_GPA_MFPH_PA12MFP_USB_VBUS | SYS_GPA_MFPH_PA13MFP_USB_D_N | SYS_GPA_MFPH_PA14MFP_USB_D_P);

    /* Set GPB multi-function pins for UART0 RXD and TXD */
    SYS->GPB_MFPH &= ~(SYS_GPB_MFPH_PB12MFP_Msk | SYS_GPB_MFPH_PB13MFP_Msk);
    SYS->GPB_MFPH |=  (SYS_GPB_MFPH_PB12MFP_UART0_RXD | SYS_GPB_MFPH_PB13MFP_UART0_TXD);

    /* Set GPB and GPC multi-function pins for codec */
    SYS->GPB_MFPL &= ~(SYS_GPB_MFPL_PB1MFP_Msk | SYS_GPB_MFPL_PB2MFP_Msk |
    				   SYS_GPB_MFPL_PB3MFP_Msk | SYS_GPB_MFPL_PB4MFP_Msk | SYS_GPB_MFPL_PB5MFP_Msk);
    SYS->GPB_MFPL |=  (SYS_GPB_MFPL_PB1MFP_I2S0_LRCK | SYS_GPB_MFPL_PB2MFP_I2S0_DO |
    				   SYS_GPB_MFPL_PB3MFP_I2S0_DI   | SYS_GPB_MFPL_PB4MFP_I2S0_MCLK | SYS_GPB_MFPL_PB5MFP_I2S0_BCLK);
    SYS->GPC_MFPL &= ~(SYS_GPC_MFPL_PC0MFP_Msk | SYS_GPC_MFPL_PC1MFP_Msk);
    SYS->GPC_MFPL |=  (SYS_GPC_MFPL_PC0MFP_I2C0_SDA | SYS_GPC_MFPL_PC1MFP_I2C0_SCL);
    /* Enable schmitt trigger avoid from disturb */
    PB->SMTEN |= GPIO_SMTEN_SMTEN5_Msk;
    PC->SMTEN |= GPIO_SMTEN_SMTEN1_Msk;
}

/* Init I2C interface */
void I2C0_Init(void)
{
    /* Open I2C2 and set clock to 100k */
    I2C_Open(I2C0, 100000);

    /* Get I2C2 Bus Clock */
    printf("I2C clock  %d Hz\n", I2C_GetBusClockFreq(I2C0));
}

/* Init I2S interface */
void I2S0_Init(void)
{
    /* Open I2S0 as slave mode */
    I2S_Open(I2S0, I2S_MODE_SLAVE, 48000, I2S_DATABIT_16, I2S_DISABLE_MONO, I2S_FORMAT_I2S);

    /* Set MCLK and enable MCLK */
    printf("I2S MCLK %d Hz\r\n", I2S_EnableMCLK(I2S0, 12000000));
}

void main(void)
{
    q15_t q15sineTable[48];
    uint32_t index, data = 0;

    /* Unlock protected registers */
    SYS_UnlockReg();

    /* Init System, peripheral clock and multi-function I/O */
    SYS_Init();

    /* Lock protected registers */
    SYS_LockReg();

    /* Init UART to 115200-8n1 for print message */
    UART_Open(UART0, 115200);

    /* Connect UART to PC, and open a terminal tool to receive following message */
    printf("\r\nFunction generator.\r\n");

    /* Init I2C0 */
    I2C0_Init();

    /* Init I2S0 */
    I2S0_Init();

    /* Reset the audio codec by software */
    NAU88L25_Reset();

    /* Initialize NAU88L25 codec */
    NAU88L25_Setup();

    /*
    printf("Select a waveform.\r\n");
    printf("[0] Square wave\r\n");
    printf("[1] Triangle wave\r\n");
    printf("[2] Sine wave\r\n");

    printf("\r\nEnter a frequency between 20 Hz and 20000 Hz: ");
    */

    /* Create sine table */
    for (int p=0; p<48; p++)
    {
        q15_t t = 32768UL*p/48;
        q15sineTable[p] = arm_sin_q15(t);
        printf("%02d: arm_sin_q15(%d) = 0x%04x\r\n", p, t, (uint16_t)q15sineTable[p]);
    }

    I2S_CLR_TX_FIFO(I2S0);
    I2S_ENABLE_TX(I2S0);

    /* Fill I2S_TXFIFO */
    while (1)
    {
        /* Check if I2S_TXFIFO is not full */
        if (I2S_GET_INT_FLAG(I2S0, I2S_STATUS0_TXFULL_Msk) == 0)
        {
            /* Write left and right channel with same data */
            data = (uint32_t)q15sineTable[index] << 16;
            data |= (uint32_t)q15sineTable[index] & 0xFFFFUL;
            I2S_WRITE_TX_FIFO(I2S0, data);

            //printf("%02d: 0x%08x\n", index, data);

            /* Increase or loop back the index */
            index++;
            if (index >= 48)
                index = 0;
        }        
    }
}

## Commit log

2021-08-15 Upload KiCad files
    [2137160001.sch, 2137160001.stp, 2SJ3080-000111F.stp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]
2021-08-15 reorganize directory, add PCB image
    [2137160001.sch, 2137160001.stp, 2SJ3080-000111F.stp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]
2021-08-15 Adjust the order of schematic
    [NuDAC.sch]
2021-08-16 Update schematic PDF
2021-09-11 Change detect pin into PA15
2021-09-11 Fix SysTick->LOAD overflow issue
    [main.c]
2021-10-06 Add replacement part number for level shifter
    [file608CB110.sch]
2022-01-01 Change pin mode resolving method
2022-01-02 Fix HIRC stability issue
    [main.c]
2022-01-02 Fix HIRC stability and SysTick overflow issue
    [main.c]
2022-01-02 Add return value avoid from warnimg
    [main.c]
2022-01-02 Add silkscreen comment
    [NuDAC.kicad_pcb]
2022-01-16 Fix carriage return mistake
    [main.c]
2022-01-27 Update print message
2022-10-02 Update to KiCad 6
    [2137160001.kicad_sch, NAU88L25YGB.kicad_sch, NuDAC.kicad_pcb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]
